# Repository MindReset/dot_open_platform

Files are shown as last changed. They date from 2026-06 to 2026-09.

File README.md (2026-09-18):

# Dot Open Platform

Dot Open Platform is the public resource repository for MindReset open devices and device capabilities. It provides mechanical files, firmware bring-up resources, pin maps, display integration notes, local device protocols, examples, and machine-readable metadata for platforms that present or index Dot device materials.

Resources cover Quote/0 hardware, Rand/0 local Display Mode, and Read Pico enclosure design and firmware development.

## Available Resources

| Product | Package | Included resources |
| --- | --- | --- |
| Quote/0 | `devices/quote_0/` | Enclosure STEP and AdventureX 2026 badge STL files, ESP32-C3 GPIO map, standard and Early Bird Edition display drivers, display waveform/LUT notes, ESP-IDF example, developer documentation |
| Rand/0 Display Mode | `capabilities/rand_0_display_mode/` | Local WebSocket protocol reference and an official browser image-sending example |
| Read Pico | [devices/read_0/](devices/read_0/README.md) | Enclosure STEP model and mechanical notes; official demo firmware, board support, drivers, and pinout links |

## Quick Links

### Quote/0

- [Quote/0 device package](devices/quote_0/README.md)
- [Quote/0 manifest](devices/quote_0/manifest.json)
- [Quote/0 enclosure resources](devices/quote_0/enclosure/README.md)
- [Quote/0 enclosure STEP](devices/quote_0/enclosure/step/quote_0-enclosure.step)
- [AdventureX 2026 badge front STL](devices/quote_0/enclosure/stl/adventurex-2026/quote_0-adventurex-2026-badge-front.stl)
- [AdventureX 2026 badge back cover STL](devices/quote_0/enclosure/stl/adventurex-2026/quote_0-adventurex-2026-badge-back-cover.stl)
- [Quote/0 GPIO pinout](devices/quote_0/firmware-resources/gpio/pinout.md)
- [Display resources](devices/quote_0/firmware-resources/display/README.md)
- [Display driver selection](devices/quote_0/firmware-resources/display/driver-selection.md)
- [Custom firmware guide](devices/quote_0/docs/custom-firmware-guide.md)

### Rand/0

- [Rand/0 Display Mode capability](capabilities/rand_0_display_mode/README.md)
- [Rand/0 browser example](capabilities/rand_0_display_mode/examples/web/display_ws_test.html)

### Read Pico

- [Read Pico hardware and firmware entry](devices/read_0/README.md)
- [Read Pico enclosure resources](devices/read_0/enclosure/README.md)
- [Read Pico enclosure STEP](devices/read_0/enclosure/step/read_0-enclosure.step)
- [Read Pico official firmware repository](https://github.com/MindReset/read_pico_firmware)

### Repository

- [Repository license](LICENSE.md)
- [Authors](AUTHORS)
- [Maintainers](MAINTAINERS)

## Official Online Resources

For a product-level overview of the Dot developer ecosystem, visit the [Dot Developer Platform](https://dot.mindreset.tech/developers).

The links below point to reference documentation and community resources that are most relevant when using this repository:

### Product Documentation

| Resource | What it helps you do |
| --- | --- |
| [Quote/0 Docs](https://dot.mindreset.tech/docs/quote_0) | Learn how Quote/0 works, including setup, firmware, and user-facing device behavior. |
| [Rand/0 Docs](https://dot.mindreset.tech/docs/rand_0) | Device features, setup, and local Display Mode. |
| [Read Pico Docs](https://dot.mindreset.tech/docs/read_0) | Product specifications, official demos, and firmware development. |

### Developer APIs and Skills

| Resource | What it helps you do |
| --- | --- |
| [Developer Platform Docs](https://dot.mindreset.tech/docs/service/open) | Create API keys, find device IDs, read device status, update device settings, and control device content. |
| [Text API](https://dot.mindreset.tech/docs/service/open/text_api) | Send text content to Dot devices. |
| [Image API](https://dot.mindreset.tech/docs/service/open/image_api) | Send image content to Dot devices. |
| [Canvas API](https://dot.mindreset.tech/docs/service/open/canvas_api) | Create structured visual content for Dot devices. |
| [Skills](https://dot.mindreset.tech/docs/service/open/skill) | Build reusable device content workflows. |

### Content and Community

| Resource | What it helps you do |
| --- | --- |
| [Content Studio](https://dot.mindreset.tech/docs/service/studio) | Create and manage rich Dot content without writing a full firmware stack. |
| [Community Co-Creation](https://dot.mindreset.tech/docs/service/co_create) | Browse community-built Dot integrations and examples. |
| [Software Co-Creation](https://dot.mindreset.tech/docs/service/co_create/software) | Explore API clients, automations, MCP integrations, dashboards, and software workflows. |
| [Hardware Co-Creation](https://dot.mindreset.tech/docs/service/co_create/hardware) | Explore community mounts, stands, cases, and other hardware accessories. |

## Repository Layout

```text
devices/
  quote_0/
    README.md
    manifest.json
    enclosure/
    firmware-resources/
    docs/
    examples/
  read_0/
    README.md
    manifest.json
    enclosure/
capabilities/
  rand_0_display_mode/
    README.md
    protocol.md
    examples/
```

Each device package is intended to be useful in two ways:

1. People can read the documentation directly on GitHub or another public platform.
2. Tools can read `manifest.json` to locate downloadable files and device metadata.

## What Is Included for Quote/0

- A STEP enclosure model exported in millimeter units.
- A two-part AdventureX 2026 badge enclosure provided as binary STL meshes.
- GPIO documentation for the ESP32-C3 pins used by the current Quote/0 hardware design.
- Minimal ESP-IDF display drivers for the 152 x 296 monochrome e-paper display.
- Documentation for selecting the standard or Early Bird Edition display driver.
- Documentation for the included full-refresh waveform/LUT data.
- A minimal ESP-IDF example showing how to initialize and refresh the display.
- Licensing, attribution, contribution, support, and security documentation.

## What Is Included for Rand/0 Display Mode

- A protocol reference for the Rand/0 `200 × 200` local display endpoints.
- An official dependency-free browser example for sending black-and-white or four-level grayscale images.
- Button event handling and local-network security guidance.

## Using These Materials

Start with the [Quote/0 getting started guide](devices/quote_0/docs/getting-started.md). If you are building custom firmware, continue with the [custom firmware guide](devices/quote_0/docs/custom-firmware-guide.md) and the [display integration guide](devices/quote_0/docs/display-integration.md).

If you are working on the enclosure, start with the [enclosure README](devices/quote_0/enclosure/README.md) and inspect the applicable STEP or STL files in your CAD or slicing tool before manufacturing or printing.

If you are building a local Rand/0 display tool, start with the [Rand/0 Display Mode capability](capabilities/rand_0_display_mode/README.md) and its [protocol reference](capabilities/rand_0_display_mode/protocol.md).

For Read Pico, start with the [resource entry](devices/read_0/README.md). Use the [enclosure resources](devices/read_0/enclosure/README.md) for custom cases and accessories, or continue in the [official firmware repository](https://github.com/MindReset/read_pico_firmware) for firmware development.

## License Summary

This repository uses multiple licenses:

- Software source code: Apache-2.0
- Hardware design material: CERN-OHL-P-2.0
- Documentation and media: CC BY 4.0

See [LICENSE.md](LICENSE.md) and [NOTICE.md](NOTICE.md) before redistributing modified material.

## No Warranty

These resources are provided as open hardware reference material. Verify electrical limits, enclosure tolerances, battery handling, and display behavior before using the files in a production or safety-sensitive context.

MindReset cannot guarantee the security of custom firmware flashed to devices. Flashing custom firmware voids the device warranty. Device-specific safety notes are documented in each custom firmware guide, starting with the [Quote/0 custom firmware guide](devices/quote_0/docs/custom-firmware-guide.md).

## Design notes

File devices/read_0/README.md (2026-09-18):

# Read Pico

Read Pico is an ESP32-S3 development board with a 4.7-inch e-paper display, native 16-level grayscale, two-point touch, three touch keys, microSD storage, and USB-C. The product belongs to the Read series.

## Official firmware and hardware references

**[Open the official demo firmware repository](https://github.com/MindReset/read_pico_firmware)**

The firmware repository contains the factory demo, board support, chip drivers, pin assignments, display waveforms, and ESP-IDF build instructions. Its demos cover display refresh, touch, acceleration, power, storage, fonts, and sleep/wake behavior.

This Open Platform package includes the enclosure model and links to firmware resources. Firmware, drivers, and firmware assets are maintained in the dedicated repository and are not duplicated here.

| Resource | Link |
| --- | --- |
| Enclosure model and mechanical notes | [Enclosure resources](enclosure/README.md) |
| Enclosure STEP download | [read_0-enclosure.step](enclosure/step/read_0-enclosure.step) |
| Official firmware, board support, and pinout | [read_pico_firmware](https://github.com/MindReset/read_pico_firmware) |
| Product documentation | [Read Pico](https://dot.mindreset.tech/docs/read_0) |
| Official demo guide | [Getting started](https://dot.mindreset.tech/docs/read_0/start) |
| Build and flash | [Firmware guide](https://dot.mindreset.tech/docs/read_0/firmware) |
| Machine-readable resource index | [manifest.json](manifest.json) |

The firmware currently requires ESP-IDF v6.1 and targets ESP32-S3. Follow its README for board-specific timing and VCOM handling. Firmware and bundled components follow the licenses in that repository; this entry does not relicense those resources.

## Enclosure and Accessories

Use the [enclosure STEP model](enclosure/step/read_0-enclosure.step) to design custom cases, mounts, and accessories. The model uses millimeter units and is provided in STEP AP242 format.

Read the [enclosure notes](enclosure/README.md) before modifying or manufacturing parts. The enclosure is licensed under CERN-OHL-P-2.0; documentation follows CC BY 4.0.

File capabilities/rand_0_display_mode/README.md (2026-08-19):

# Rand/0 Display Mode

Rand/0 Display Mode lets you build a small local tool that sends custom images to the device and receives its button events. It is a direct LAN connection: no Dot. App, Dot API, or custom firmware is required.

This package documents the Display Mode protocol implemented by Rand/0 firmware `1.3.1` and includes an official browser example.

## Quick start

Before you begin:

- Complete Wi-Fi Time Sync once so Rand/0 remembers a Wi-Fi network.
- Keep Rand/0 charged or connected to power.
- Connect your computer and Rand/0 to the same local network.

1. On Rand/0, open **Main menu → More → Display**.
2. Wait for the device to show its local IP address.
3. Serve the browser example from this directory:

   ```sh
   cd examples/web
   python3 -m http.server 8765
   ```

4. Open <http://127.0.0.1:8765/display_ws_test.html>.
5. Enter the IP address shown on Rand/0, connect, choose an image, and send it.

The device exits Display Mode when you long-press the top button.

## Example

- [Browser example](examples/web/display_ws_test.html)
- [Protocol reference](protocol.md)

The example is a dependency-free HTML file. It resizes an image to `200 × 200`, converts it to the selected frame format in the browser, sends it over WebSocket, and displays button events returned by Rand/0.

## Network and security

Display Mode is intended for a trusted local network. The device exposes its WebSocket endpoints without additional login authentication. Do not forward the device port to the internet or send sensitive content while using this capability.

The device allows one active client at a time. A new connection replaces the previous one, and frames sent faster than the e-ink display can refresh may be dropped so that only the latest frame is kept.

This is a device-local capability, not a Dot cloud API. It does not provide device identity, remote access, or firmware customization.

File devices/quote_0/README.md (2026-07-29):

# Quote/0

Quote/0 is a smart e-ink Dot device published by MindReset. It is designed for calm, glanceable information in everyday spaces and can display app-configured content such as RSS feeds, to-dos, calendars, weather, and custom API-driven updates.

This open device package collects the public files needed to inspect the enclosure, understand the hardware pin map, and build custom firmware that drives the e-paper display.

## Package Contents

| Area | Path | Contents |
| --- | --- | --- |
| Device metadata | `manifest.json` | Machine-readable device and asset index |
| Enclosure | `enclosure/` | Main STEP model, AdventureX 2026 badge STL files, and mechanical documentation |
| GPIO | `firmware-resources/gpio/` | ESP32-C3 pinout in Markdown, CSV, and JSON |
| Display | `firmware-resources/display/` | Standard and Early Bird Edition display drivers, waveform/LUT notes, and integration docs |
| Guides | `docs/` | Getting started, hardware overview, custom firmware, display integration, enclosure notes, FAQ |
| Examples | `examples/` | Minimal ESP-IDF display example |

## Hardware Summary

| Item | Value |
| --- | --- |
| Main MCU | ESP32-C3 |
| Display controller | UC8251D for standard edition; UC8151/IL0324 for Early Bird Edition |
| Display resolution | 152 x 296 |
| Display colors | 1-bit monochrome, white/black |
| Display buffer size | 5,624 bytes |
| Display bus | SPI, MOSI-only, no MISO |
| Console | USB-Serial-JTAG |
| Enclosure files | STEP AP242 exchange file and binary STL meshes |

## Official Online Resources

| Resource | Link |
| --- | --- |
| Developer Platform | https://dot.mindreset.tech/developers |
| Quote/0 product docs | https://dot.mindreset.tech/docs/quote_0 |
| Developer Platform docs | https://dot.mindreset.tech/docs/service/open |
| Text API | https://dot.mindreset.tech/docs/service/open/text_api |
| Image API | https://dot.mindreset.tech/docs/service/open/image_api |
| Canvas API | https://dot.mindreset.tech/docs/service/open/canvas_api |
| Skills | https://dot.mindreset.tech/docs/service/open/skill |
| Content Studio | https://dot.mindreset.tech/docs/service/studio |
| Community Co-Creation | https://dot.mindreset.tech/docs/service/co_create |
| Software Co-Creation | https://dot.mindreset.tech/docs/service/co_create/software |
| Hardware Co-Creation | https://dot.mindreset.tech/docs/service/co_create/hardware |

## Quick Start

1. Review the [getting started guide](docs/getting-started.md).
2. Check the [GPIO pinout](firmware-resources/gpio/pinout.md).
3. Read the [display resources](firmware-resources/display/README.md).
4. Try the [ESP-IDF minimal display example](examples/esp-idf/minimal-display/README.md).
5. Review the [enclosure resources](enclosure/README.md) and inspect the applicable STEP or STL files in your CAD or slicing tool.

## Firmware Bring-Up Path

For a custom firmware port, start with the files in this order:

1. `firmware-resources/gpio/pinout.md`
2. `firmware-resources/display/driver-selection.md`
3. `firmware-resources/display/README.md`
4. Standard edition: `firmware-resources/display/drivers/uc8251d_minimal.h` and `firmware-resources/display/drivers/uc8251d_minimal.c`
5. Early Bird Edition: `firmware-resources/display/drivers/uc8151_minimal.h` and `firmware-resources/display/drivers/uc8151_minimal.c`
6. `examples/esp-idf/minimal-display/`

The minimal display drivers are intentionally small. They focus on initializing the selected panel, sending a full-frame 1bpp buffer, clearing the panel, and entering sleep.

## Custom Firmware Safety

MindReset cannot guarantee the security of custom firmware flashed to Quote/0, and flashing custom firmware voids the device warranty. Before building firmware, read the [custom firmware guide](docs/custom-firmware-guide.md), especially the ESP-IDF console configuration, deep-sleep recovery, and power-on sequence notes.

Use Pure USB Serial/JTAG for ESP-IDF console output. The default UART console pins may conflict with `GPIO20`, which controls display power.

## Mechanical Files

The package includes the main Quote/0 STEP enclosure model and a two-part AdventureX 2026 badge enclosure:

```text
enclosure/step/quote_0-enclosure.step
enclosure/stl/adventurex-2026/quote_0-adventurex-2026-badge-front.stl
enclosure/stl/adventurex-2026/quote_0-adventurex-2026-badge-back-cover.stl
```

The STEP file supports inspection, derivative mechanical work, and manufacturing preparation. The AdventureX 2026 binary STL files provide a printable front shell and back cover. Always verify units, tolerances, wall thicknesses, mounting features, and material behavior before production.

## Platform Metadata

Platforms that need a stable inventory should read:

```text
devices/quote_0/manifest.json
```

The manifest lists the device name, hardware summary, resource paths, license scopes, and files included in the current public package.

## Licensing

- Software source code: Apache-2.0
- Hardware design material: CERN-OHL-P-2.0
- Documentation and media: CC BY 4.0

See the repository [license](../../LICENSE.md) and [notice](../../NOTICE.md) for details.

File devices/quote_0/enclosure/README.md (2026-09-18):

# Quote/0 Enclosure

This folder contains public mechanical resources for the Quote/0 enclosure.

## Included Files

| File | Format | Notes |
| --- | --- | --- |
| `step/quote_0-enclosure.step` | STEP AP242 | Main Quote/0 enclosure, exported from Shapr3D in millimeter units |
| `stl/adventurex-2026/quote_0-adventurex-2026-badge-front.stl` | Binary STL | AdventureX 2026 badge enclosure front shell |
| `stl/adventurex-2026/quote_0-adventurex-2026-badge-back-cover.stl` | Binary STL | AdventureX 2026 badge enclosure back cover |

The STEP header identifies MindReset and Quote/0, includes the source URL and license identifier, and preserves the export timestamp `2026-06-12T22:04:06+08:00`.

## Folder Layout

| Folder | Purpose |
| --- | --- |
| `step/` | STEP exchange files |
| `stl/adventurex-2026/` | Printable meshes for the AdventureX 2026 badge enclosure |

## AdventureX 2026 Badge Enclosure

The AdventureX 2026 badge enclosure is an alternate two-part Quote/0 shell created for the AdventureX 2026 hackathon. Use the front shell and back cover together.

Design credit: [AdventureX 2026](https://adventure-x.org/en). Published by MindReset.

Each binary STL header identifies MindReset, Quote/0, the part, AdventureX 2026 as the designer, and CERN-OHL-P-2.0. Binary STL headers are limited to 80 bytes; full source and attribution details are provided here.

- Source: [MindReset Dot Open Platform](https://github.com/MindReset/dot_open_platform)
- Official website: [Dot by MindReset](https://dot.mindreset.tech)

These STEP and STL file-level markings do not add an embossed or engraved logo to the geometry.

## Usage Notes

- Inspect the STEP file in a CAD tool before machining, printing, or modifying the design.
- STL files do not encode units. Import the AdventureX 2026 meshes as millimeters and verify their scale before printing.
- Confirm tolerances against the exact display, PCB, battery, fasteners, and materials you use.
- STEP is an exchange format. If you need parametric editing, rebuild the model in your CAD tool or wait for a native source file release.
- No official drawing, render, or print profile is included. Print orientation, material, nozzle size, shrinkage, and post-processing all affect the result.

## License

Hardware design material in this folder is licensed under [CERN-OHL-P-2.0](../../../LICENSES/CERN-OHL-P-2.0.txt) unless a file states otherwise.

When redistributing modified designs, credit MindReset and retain the AdventureX design credit for the badge enclosure. See [NOTICE.md](../../../NOTICE.md) and the [trademark terms](../../../LICENSE.md#trademarks).

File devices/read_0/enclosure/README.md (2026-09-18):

# Read Pico Enclosure

Use the Read Pico enclosure model to design custom cases, mounts, and accessories.

## Included Files

| File | Format | Notes |
| --- | --- | --- |
| [read_0-enclosure.step](step/read_0-enclosure.step) | STEP AP242 | Read Pico enclosure, exported from Shapr3D in millimeter units; contains two solid bodies |

The source model was exported on `2026-09-17T18:39:30+08:00`. The STEP header identifies MindReset and Read Pico and includes the source URL and license identifier. These file-level markings do not add an embossed or engraved logo to the geometry.

## Usage Notes

- Open the STEP file in your CAD tool with millimeter units to inspect or modify the enclosure.
- Check dimensions, wall thickness, assembly clearances, display alignment, and access to ports and controls against your actual device before manufacturing.
- Confirm fit and tolerances for your chosen materials and process when designing cases, mounts, or other accessories.
- STEP is a CAD exchange format, not a native parametric source file. Rebuild editable features as needed in your CAD tool.
- No STL export, dimensioned drawing, or print profile is included. Export your modified design to a suitable format and verify its scale before printing or machining.

## License and Attribution

Hardware design material in this folder is licensed under [CERN-OHL-P-2.0](../../../LICENSES/CERN-OHL-P-2.0.txt).

Recommended attribution:

```text
This project is based on Read Pico enclosure design and public materials by MindReset.
Hardware source: MindReset
Official link: https://dot.mindreset.tech
```

See [NOTICE.md](../../../NOTICE.md) and the [trademark terms](../../../LICENSE.md#trademarks) when redistributing modified designs.

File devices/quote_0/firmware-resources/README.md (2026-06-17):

# Quote/0 Firmware Resources

This folder contains the public hardware-facing files needed to bring up custom Quote/0 firmware.

## Contents

| Folder | Purpose |
| --- | --- |
| `gpio/` | ESP32-C3 pin usage table in human-readable and machine-readable formats |
| `display/` | Standard and Early Bird Edition e-paper drivers, display constants, waveform/LUT notes, and initialization guidance |

## Firmware Assumptions

- MCU: ESP32-C3
- Console: Pure USB Serial/JTAG, with `ESP_CONSOLE_UART_DEFAULT` disabled and `ESP_CONSOLE_USB_SERIAL_JTAG` enabled
- Display bus: SPI using MOSI and CLK, with no MISO line
- Display power is controlled by a dedicated GPIO
- Display framebuffer format is 1 bit per pixel, where `1` means white and `0` means black

These files are intended as reference material. Verify the exact hardware revision before using them in production firmware.

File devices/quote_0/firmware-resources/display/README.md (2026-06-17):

# Quote/0 Display Resources

Quote/0 uses a 152 x 296 monochrome e-paper display. There are two display driver variants: the standard edition uses the UC8251D driver, while the Early Bird Edition uses the UC8151/IL0324 driver.

Before porting firmware, read [driver-selection.md](driver-selection.md) and choose the driver that matches the edition shown in the Dot. App device details.

## Display Summary

| Item | Value |
| --- | --- |
| Controller | UC8251D for standard edition; UC8151/IL0324 for Early Bird Edition |
| Resolution | 152 x 296 |
| Color mode | Black and white |
| Pixel format | 1 bit per pixel |
| Pixel value | `1 = white`, `0 = black` |
| Framebuffer size | 5,624 bytes |
| Bus | SPI |

## Files

| Path | Purpose |
| --- | --- |
| `driver-selection.md` | Rules for choosing the standard or Early Bird Edition display driver |
| `drivers/uc8251d_minimal.h` | Standard edition public interface and display configuration structure |
| `drivers/uc8251d_minimal.c` | Standard edition ESP-IDF implementation for UC8251D full-frame refresh |
| `drivers/uc8151_minimal.h` | Early Bird Edition public interface and display configuration structure |
| `drivers/uc8151_minimal.c` | Early Bird Edition ESP-IDF implementation for UC8151/IL0324 full-frame refresh |
| `waveforms/README.md` | Notes on the included full-refresh waveform/LUT data |
| `init-sequences/README.md` | Initialization sequence notes |

## Standard Edition Minimal Usage

Use this path unless the Dot. App device details show the Early Bird Edition label.

```c
#include <string.h>
#include "uc8251d_minimal.h"

static const uc8251d_config_t display_config = {
    .spi_host = SPI2_HOST,
    .pin_vin = 20,
    .pin_busy = 3,
    .pin_reset = 4,
    .pin_dc = 5,
    .pin_cs = 6,
    .pin_sck = 10,
    .pin_mosi = 7,
    .spi_clock_hz = 15 * 1000 * 1000,
};

void app_main(void)
{
    uc8251d_init(&display_config);
    uc8251d_clear(true);

    uint8_t frame[UC8251D_BUFFER_SIZE];
    memset(frame, 0xFF, sizeof(frame));

    uc8251d_display(frame);
    uc8251d_sleep();
}
```

## Early Bird Edition Minimal Usage

Use this path only when the Dot. App device details show `首发版`, `Early Bird Edition`, or `先発版です`.

```c
#include <string.h>
#include "uc8151_minimal.h"

static const uc8151_config_t display_config = {
    .spi_host = SPI2_HOST,
    .pin_vin = 20,
    .pin_busy = 3,
    .pin_reset = 4,
    .pin_dc = 5,
    .pin_cs = 6,
    .pin_sck = 10,
    .pin_mosi = 7,
    .spi_clock_hz = 15 * 1000 * 1000,
};

void app_main(void)
{
    uc8151_init(&display_config);
    uc8151_clear(true);

    uint8_t frame[UC8151_BUFFER_SIZE];
    memset(frame, 0xFF, sizeof(frame));

    uc8151_display(frame);
    uc8151_sleep();
}
```

## Scope

The minimal drivers only cover the public bring-up paths needed by Quote/0:

- SPI bus setup.
- Panel reset and busy polling.
- Full-frame 1bpp refresh.
- White or black clear.
- Display sleep and power control.

It does not include automatic display detection, multi-panel abstraction, image decoding, partial refresh, UI rendering, or application logic.

## License

Driver source files are licensed under Apache-2.0. Display hardware notes and waveform documentation are licensed under CERN-OHL-P-2.0 or CC BY 4.0 according to the repository license policy.

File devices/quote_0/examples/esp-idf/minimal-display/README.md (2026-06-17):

# Quote/0 ESP-IDF Minimal Display Example

This example shows how to initialize the standard edition Quote/0 UC8251D display, write a simple 1bpp pattern, refresh the screen, and enter sleep.

If the Dot. App device details show `首发版`, `Early Bird Edition`, or `先発版です`, use the Early Bird Edition UC8151/IL0324 driver instead. See:

```text
../../../firmware-resources/display/driver-selection.md
```

## Requirements

- ESP-IDF installed and configured.
- Quote/0 hardware or compatible wiring.
- Standard edition UC8251D display with the Quote/0 152 x 296 monochrome panel configuration.

## Files

| File | Purpose |
| --- | --- |
| `CMakeLists.txt` | ESP-IDF project file |
| `main/CMakeLists.txt` | Main component definition |
| `main/quote_0_minimal_display_example.c` | Example application |

The example builds against the public driver in:

```text
../../../firmware-resources/display/drivers/
```

## Usage

From this folder, use the normal ESP-IDF flow:

```sh
idf.py set-target esp32c3
idf.py build
idf.py flash monitor
```

## Expected Behavior

The firmware clears the screen to white, draws a small black border pattern into a framebuffer, refreshes the display, and enters display sleep.

## Notes

- The example does not configure Wi-Fi, Bluetooth LE, storage, or application UI.
- If your hardware wiring differs from Quote/0, update `display_config` in the example source file.
- If the display does not refresh, check power, reset, BUSY, CS, MOSI, CLK, and the SPI host.

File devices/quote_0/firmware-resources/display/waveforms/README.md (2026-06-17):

# Quote/0 Waveform Notes

Quote/0 includes separate waveform/LUT data for the standard edition and the Early Bird Edition.

Use the waveform data only with the matching display driver. The screen parameters are the same, but the controller firmware and waveform requirements differ.

## Driver Selection

Use the Early Bird Edition waveform only when the Dot. App device details show `首发版`, `Early Bird Edition`, or `先発版です`.

If the device details do not show one of these edition labels, use the standard edition waveform.

## Standard Edition LUT

The standard edition UC8251D driver includes a full-refresh waveform/LUT table named `s_lut_gc` in:

```text
../drivers/uc8251d_minimal.c
```

The waveform data is redistributed here as part of the public Quote/0 display resources, based on the assumption that MindReset is authorized to publish and redistribute it.

### LUT Layout

The table contains 376 bytes split across the UC8251D LUT command registers:

| Command | Offset | Length |
| --- | ---: | --- |
| `0x20` | `0` | `80` |
| `0x21` | `80` | `56` |
| `0x22` | `136` | `80` |
| `0x23` | `216` | `80` |
| `0x24` | `296` | `80` | 

The driver loads the LUT before writing the old and new frame planes, then triggers a full display update with command `0x12`.

## Early Bird Edition LUT

The Early Bird Edition UC8151/IL0324 driver stores separate full-refresh LUT arrays in:

```text
../drivers/uc8151_minimal.c
```

| Command | Array | Length |
| --- | --- | --- |
| `0x20` | `s_lut_vcom` | `44` |
| `0x21` | `s_lut_ww` | `42` | 
| `0x22` | `s_lut_bw` | `42` | 
| `0x23` | `s_lut_wb` | `42` | 
| `0x24` | `s_lut_bb` | `42` | 

The Early Bird Edition driver loads the LUT during panel initialization, then triggers a full display update with command `0x12`.

## Integration Rules

- Use each LUT with its matching driver and the Quote/0 152 x 296 monochrome panel configuration.
- Keep the framebuffer format as 1bpp, where `1` means white and `0` means black.
- If you replace the display panel, validate the controller, resolution, voltage behavior, and waveform requirements before reusing this LUT.

## License

Waveform-related display resources in this package are published under the repository hardware/documentation license policy. Check `LICENSE.md` and `NOTICE.md` before redistributing modified versions.

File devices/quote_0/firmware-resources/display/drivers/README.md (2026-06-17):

# Quote/0 Minimal Display Drivers

This folder contains minimal ESP-IDF display drivers for Quote/0.

Quote/0 uses two display driver variants. The screen size and framebuffer format are the same, but the controller firmware and waveform data differ.

## Which Driver to Use

Use the standard driver unless the Dot. App device details show an Early Bird Edition label.

| Dot. App locale | Device name | Edition label | Driver |
| --- | --- | --- | --- |
| `zh-Hans-CN` | `摘录/0` | `首发版` | `uc8151_minimal.*` |
| `en-US` | `Quote/0` | `Early Bird Edition` | `uc8151_minimal.*` |
| `ja-JP` | `Quote/0` | `先発版です` | `uc8151_minimal.*` |

If the device details do not show one of the edition labels above, use the standard driver:

```text
uc8251d_minimal.*
```

## Files

| File | Purpose |
| --- | --- |
| `uc8251d_minimal.h` | Standard edition public interface, dimensions, buffer size, and GPIO configuration structure |
| `uc8251d_minimal.c` | Standard edition UC8251D SPI/GPIO implementation, initialization sequence, full-refresh waveform/LUT, clear, display, and sleep functions |
| `uc8151_minimal.h` | Early Bird Edition public interface, dimensions, buffer size, and GPIO configuration structure |
| `uc8151_minimal.c` | Early Bird Edition UC8151/IL0324 SPI/GPIO implementation, initialization sequence, full-refresh waveform/LUT, clear, display, and sleep functions |

## Standard Edition API

```c
esp_err_t uc8251d_init(const uc8251d_config_t *config);
esp_err_t uc8251d_display(const uint8_t *data);
esp_err_t uc8251d_clear(bool white);
esp_err_t uc8251d_sleep(void);
```

## Early Bird Edition API

```c
esp_err_t uc8151_init(const uc8151_config_t *config);
esp_err_t uc8151_display(const uint8_t *data);
esp_err_t uc8151_clear(bool white);
esp_err_t uc8151_sleep(void);
```

## Framebuffer Format

- Width: `152`
- Height: `296`
- Buffer size: `5624` bytes
- Pixel format: 1 bit per pixel
- Pixel value: `1 = white`, `0 = black`

## Porting Notes

- Change the selected config type if your GPIO wiring differs from Quote/0.
- Keep MISO disabled unless your hardware adds a display read path.
- Keep the display power pin high while resetting, writing, and refreshing the panel.
- Call the matching sleep function after refresh if your firmware needs low-power behavior.

## License

The driver source code is licensed under Apache-2.0.

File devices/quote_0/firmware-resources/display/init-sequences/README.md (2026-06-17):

# Quote/0 Display Initialization Sequence Notes

The public initialization sequences are implemented in:

```text
../drivers/uc8251d_minimal.c
../drivers/uc8151_minimal.c
```

Use `uc8251d_minimal.*` for standard edition devices. Use `uc8151_minimal.*` only when the Dot. App device details show `首发版`, `Early Bird Edition`, or `先発版です`.

The main bring-up flow is:

1. Configure display GPIOs.
2. Enable display power through `GPIO20`.
3. Initialize the SPI bus with MOSI and CLK only.
4. Reset the panel.
5. Wait for BUSY to become ready.
6. Configure panel settings, power settings, booster soft start, resolution, PLL, TCON, VCOM, and border behavior.
7. Power on the panel and wait for BUSY.
8. Load the full-refresh LUT.
9. Write old and new image planes.
10. Trigger display refresh.
11. Enter sleep when the update is complete.

## Quote/0 Default Pins

| Signal | GPIO |
| --- | ---: |
| VIN | 20 |
| BUSY | 3 |
| RESET | 4 |
| DC | 5 |
| CS | 6 |
| MOSI | 7 |
| CLK | 10 |

## Notes

- The standard edition driver polls BUSY with command `0x71`.
- The Early Bird Edition driver polls BUSY by reading the BUSY GPIO directly.
- The default SPI clock is 15 MHz when `spi_clock_hz` is not provided.
- The display sleep path sends the controller-specific sleep sequence, then releases the display power control pin.

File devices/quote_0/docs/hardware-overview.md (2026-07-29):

# Quote/0 Hardware Overview

This overview summarizes the public hardware-facing details currently available for Quote/0.

## MCU

Quote/0 uses an ESP32-C3 MCU.

For custom ESP-IDF firmware, use Pure USB Serial/JTAG console output. The default UART console pins may conflict with `GPIO20`, which controls display power. In `menuconfig`, disable `ESP_CONSOLE_UART_DEFAULT` and enable `ESP_CONSOLE_USB_SERIAL_JTAG`.

## Power-Related Signals

| GPIO | Function | Notes |
| --- | --- | --- |
| GPIO0 | VBUS detect | High level means USB or external power is present |
| GPIO1 | Battery voltage sample | ADC input through an internal 50% / 50% resistor divider |
| GPIO20 | E-paper VIN | Controls display power |

## Display Interface

The e-paper display uses an SPI write path:

| Signal | GPIO |
| --- | ---: |
| BUSY | 3 |
| RESET | 4 |
| DC | 5 |
| CS | 6 |
| MOSI | 7 |
| CLK | 10 |
| VIN | 20 |

MISO is not used.

## Display Panel

| Item | Value |
| --- | --- |
| Standard edition controller path | UC8251D |
| Early Bird Edition controller path | UC8151/IL0324 |
| Resolution | 152 x 296 |
| Colors | White and black |
| Pixel format | 1bpp |
| Buffer size | 5,624 bytes |

The visible display parameters are the same across the standard edition and Early Bird Edition, but their controller firmware and waveform data differ. Use the Early Bird Edition driver only when the Dot. App device details show `首发版`, `Early Bird Edition`, or `先発版です`.

## Enclosure

The current mechanical release includes the main enclosure as a STEP AP242 file exported in millimeter units:

```text
enclosure/step/quote_0-enclosure.step
```

It also includes the two-part AdventureX 2026 badge enclosure as binary STL meshes:

```text
enclosure/stl/adventurex-2026/quote_0-adventurex-2026-badge-front.stl
enclosure/stl/adventurex-2026/quote_0-adventurex-2026-badge-back-cover.stl
```

## Current Public Scope

This package currently publishes the resources needed for:

- Enclosure inspection, derivative mechanical work, and printing of the AdventureX 2026 badge enclosure.
- GPIO mapping.
- Display initialization and full-frame refresh.
- Minimal ESP-IDF firmware bring-up.

It does not currently publish PCB source files, schematic PDFs, native parametric CAD files, manufacturing drawings, or complete product firmware.

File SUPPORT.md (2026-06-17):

# Support

Use GitHub issues for public questions about:

- Missing or unclear documentation.
- GPIO and display integration problems.
- Enclosure file issues.
- Example firmware bring-up problems.
- Manifest or repository structure problems.

When reporting a hardware or firmware issue, include:

- Device: `Quote/0`
- Hardware revision, if known
- Firmware framework and version, if relevant
- File path or documentation section involved
- Clear reproduction steps or photos/screenshots when useful

Do not post private credentials, API keys, unreleased supplier files, or private manufacturing documents.

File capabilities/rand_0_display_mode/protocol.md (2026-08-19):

# Rand/0 Display Mode Protocol

This document describes the WebSocket protocol implemented by Rand/0 firmware `1.3.1`.

## Connection

Enter Display Mode from **Main menu → More → Display**. Rand/0 connects to a remembered Wi-Fi network and shows its local IP address when ready.

Connect to one of these endpoints:

| Endpoint | Binary frame | Format |
| --- | ---: | --- |
| `ws://<IP>/display/bw` | Exactly `5,000` bytes | 1 bit per pixel, black and white |
| `ws://<IP>/display/gray4` | Exactly `10,000` bytes | 2 bits per pixel, four gray levels |

The display is `200 × 200` pixels. Send one binary frame for each image.

## Frame encoding

Pixels are packed row by row, from left to right and then top to bottom. The highest bits represent the leftmost pixels.

### Black and white

- `1` means white; `0` means black.
- Each byte contains 8 pixels.
- The first pixel uses bit 7.

### Four gray levels

- Each pixel uses 2 bits.
- `00` is white, `01` is light gray, `10` is dark gray, and `11` is black.
- Each byte contains 4 pixels.
- The first pixel uses bits 7–6.

## Device messages

Rand/0 sends text JSON messages for button events and errors. A short press looks like this:

```json
{"type":"key","key":"up","action":"short"}
```

Possible frame errors include:

```json
{"type":"error","error":"expected_binary_5000"}
{"type":"error","error":"expected_binary_10000"}
{"type":"error","error":"inactive_client"}
{"type":"error","error":"no_memory"}
{"type":"error","error":"queue_busy"}
```

## Limits

- Only one client is active at a time. A new connection replaces the previous client.
- If the display is still refreshing when another frame arrives, Rand/0 keeps the latest frame and may drop intermediate frames.
- The connection has no additional login authentication. Use it only on a trusted local network.

## Minimal example

```js
const socket = new WebSocket("ws://192.168.1.100/display/bw");
socket.binaryType = "arraybuffer";
socket.onopen = () => socket.send(new Uint8Array(5000).fill(0xff));
socket.onmessage = (event) => console.log(event.data);
```

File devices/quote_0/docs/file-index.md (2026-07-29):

# File Index

This index lists the public Quote/0 package files and their intended purpose.

## Device Package

| File | Purpose |
| --- | --- |
| `README.md` | Human-readable Quote/0 landing page |
| `manifest.json` | Machine-readable device and asset inventory |

## Enclosure

| File | Purpose |
| --- | --- |
| `enclosure/README.md` | Mechanical resource overview |
| `enclosure/step/quote_0-enclosure.step` | STEP enclosure model |
| `enclosure/stl/adventurex-2026/quote_0-adventurex-2026-badge-front.stl` | AdventureX 2026 badge enclosure front shell |
| `enclosure/stl/adventurex-2026/quote_0-adventurex-2026-badge-back-cover.stl` | AdventureX 2026 badge enclosure back cover |

## Firmware Resources

| File | Purpose |
| --- | --- |
| `firmware-resources/README.md` | Firmware resource overview |
| `firmware-resources/gpio/pinout.md` | Human-readable GPIO table |
| `firmware-resources/gpio/pinout.csv` | CSV GPIO table |
| `firmware-resources/gpio/pinout.json` | JSON GPIO table |
| `firmware-resources/display/README.md` | Display resource overview |
| `firmware-resources/display/driver-selection.md` | Standard vs Early Bird Edition display driver selection |
| `firmware-resources/display/drivers/README.md` | Display driver notes |
| `firmware-resources/display/drivers/uc8251d_minimal.h` | Standard edition public driver header |
| `firmware-resources/display/drivers/uc8251d_minimal.c` | Standard edition minimal driver implementation |
| `firmware-resources/display/drivers/uc8151_minimal.h` | Early Bird Edition public driver header |
| `firmware-resources/display/drivers/uc8151_minimal.c` | Early Bird Edition minimal driver implementation |
| `firmware-resources/display/waveforms/README.md` | Waveform/LUT notes |
| `firmware-resources/display/init-sequences/README.md` | Initialization sequence notes |

## Examples

| File | Purpose |
| --- | --- |
| `examples/esp-idf/minimal-display/README.md` | ESP-IDF example guide |
| `examples/esp-idf/minimal-display/CMakeLists.txt` | ESP-IDF project CMake file |
| `examples/esp-idf/minimal-display/main/CMakeLists.txt` | ESP-IDF main component CMake file |
| `examples/esp-idf/minimal-display/main/quote_0_minimal_display_example.c` | Minimal display refresh example |

## Guides

| File | Purpose |
| --- | --- |
| `docs/getting-started.md` | First steps through the package |
| `docs/hardware-overview.md` | Public hardware summary |
| `docs/custom-firmware-guide.md` | Custom firmware bring-up guide |
| `docs/display-integration.md` | Display behavior and porting guide |
| `docs/enclosure-printing.md` | Mechanical and printing notes |
| `docs/faq.md` | Common questions |
| `docs/file-index.md` | This file |

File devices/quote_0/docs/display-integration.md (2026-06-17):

# Display Integration Guide

This guide documents the display behavior exposed in the public Quote/0 package.

## Controller and Panel

Quote/0 uses a monochrome e-paper display with two driver variants. The standard edition uses the UC8251D driver path. The Early Bird Edition uses the UC8151/IL0324 driver path.

| Item | Value |
| --- | --- |
| Width | 152 pixels |
| Height | 296 pixels |
| Buffer size | 5,624 bytes |
| Color depth | 1 bit per pixel |
| White pixel | `1` |
| Black pixel | `0` |

## Driver Selection

Use the Early Bird Edition driver only when the Dot. App device details show one of these labels:

| Dot. App locale | Device name | Edition label | Driver |
| --- | --- | --- | --- |
| `zh-Hans-CN` | `摘录/0` | `首发版` | `uc8151_minimal.*` |
| `en-US` | `Quote/0` | `Early Bird Edition` | `uc8151_minimal.*` |
| `ja-JP` | `Quote/0` | `先発版です` | `uc8151_minimal.*` |

If the device details do not show one of these labels, use the standard edition driver:

```text
uc8251d_minimal.*
```

## SPI Signals

| Signal | GPIO | Direction |
| --- | ---: | --- |
| BUSY | 3 | Input |
| RESET | 4 | Output |
| DC | 5 | Output |
| CS | 6 | Output |
| MOSI | 7 | Output |
| CLK | 10 | Output |
| VIN | 20 | Output |

MISO is not used.

## Refresh Flow

The minimal drivers follow this flow:

1. Enable display power.
2. Reset the panel.
3. Wait until BUSY is ready.
4. Configure panel and power settings.
5. Load the full-refresh LUT.
6. Write the old frame plane.
7. Write the new frame plane.
8. Trigger display update.
9. Wait until BUSY is ready.
10. Enter sleep when requested.

## Waveform/LUT Data

The public full-refresh LUT data is stored in the matching driver source file:

- Standard edition: `uc8251d_minimal.c`
- Early Bird Edition: `uc8151_minimal.c`

See:

```text
firmware-resources/display/waveforms/README.md
```

Use each waveform only with the matching controller and panel configuration unless you have validated another display.

## Common Bring-Up Problems

| Symptom | Things to check |
| --- | --- |
| Display never updates | VIN pin, RESET pin, CS pin, SPI host, MOSI/CLK wiring |
| Firmware times out waiting for BUSY | BUSY pin number, pull-up configuration, panel power |
| Image is inverted | Pixel convention: `1 = white`, `0 = black` |
| Image is shifted or corrupted | Buffer size, row packing, SPI mode, transfer length |
| Display works once and then stops | Sleep path, power control, reset before next update |

## Porting Checklist

- Confirm the display variant from Dot. App device details.
- Use `uc8251d_minimal.*` for standard edition devices.
- Use `uc8151_minimal.*` for Early Bird Edition devices.
- Confirm 152 x 296 resolution.
- Confirm 1bpp framebuffer size.
- Confirm GPIO mapping.
- Confirm SPI mode 0.
- Confirm display power control behavior.
- Confirm BUSY polarity on the actual panel.

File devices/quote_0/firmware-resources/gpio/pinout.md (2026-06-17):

# Quote/0 GPIO Pinout

This document lists the ESP32-C3 GPIOs used by the current Quote/0 hardware design. Use it for firmware bring-up, hardware migration, and debugging.

## Used GPIOs

| GPIO | Function | Direction | Notes |
| --- | --- | --- | --- |
| GPIO0 | VBUS detect | Input | Detects whether USB or external power is connected. High level means external power is present. |
| GPIO1 | Battery voltage sample | Input / ADC | Reads battery voltage through an internal 50% / 50% resistor divider. |
| GPIO3 | E-paper BUSY | Input | Reads the display busy state. |
| GPIO4 | E-paper RESET | Output | Controls display reset. |
| GPIO5 | E-paper DC | Output | Selects command or data for SPI transfers. |
| GPIO6 | E-paper CS | Output | Display SPI chip select. |
| GPIO7 | E-paper MOSI | Output | Display SPI data output. |
| GPIO10 | E-paper CLK | Output | Display SPI clock. |
| GPIO20 | E-paper VIN | Output | Controls display power. |

## Notes

- The e-paper display uses SPI and does not use MISO.
- For custom ESP-IDF firmware, use Pure USB Serial/JTAG console output. The default UART console pins may conflict with `GPIO20`; disable `ESP_CONSOLE_UART_DEFAULT` and enable `ESP_CONSOLE_USB_SERIAL_JTAG`.
- Wi-Fi, Bluetooth LE, and the internal temperature sensor do not require external GPIOs.

## Machine-Readable Files

- `pinout.csv`
- `pinout.json`

## License

Hardware connection information is licensed under CERN-OHL-P-2.0. This documentation is licensed under CC BY 4.0.

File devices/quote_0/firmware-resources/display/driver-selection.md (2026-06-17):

# Quote/0 Display Driver Selection

Quote/0 has two display driver variants. The screen parameters are the same, but the controller firmware and waveform data are different.

Use the wrong display driver only after you have verified the panel yourself. For normal users and firmware ports, choose the driver based on the Dot. App device details.

## Selection Rule

Use the Early Bird Edition driver only when the Dot. App device details show one of these edition labels:

| Dot. App locale | Device name | Edition label | Driver files |
| --- | --- | --- | --- |
| `zh-Hans-CN` | `摘录/0` | `首发版` | `drivers/uc8151_minimal.h`, `drivers/uc8151_minimal.c` |
| `en-US` | `Quote/0` | `Early Bird Edition` | `drivers/uc8151_minimal.h`, `drivers/uc8151_minimal.c` |
| `ja-JP` | `Quote/0` | `先発版です` | `drivers/uc8151_minimal.h`, `drivers/uc8151_minimal.c` |

If the device details do not show one of the labels above, use the standard edition driver:

```text
drivers/uc8251d_minimal.h
drivers/uc8251d_minimal.c
```

## Variant Summary

| Variant | App label | Controller path | Driver files |
| --- | --- | --- | --- |
| Standard edition | No Early Bird Edition label | UC8251D | `uc8251d_minimal.h`, `uc8251d_minimal.c` |
| Early Bird Edition | `首发版` / `Early Bird Edition` / `先発版です` | UC8151/IL0324 | `uc8151_minimal.h`, `uc8151_minimal.c` |

## Shared Display Parameters

Both variants use the same public framebuffer shape:

| Item | Value |
| --- | --- |
| Resolution | 152 x 296 |
| Color mode | Black and white |
| Pixel format | 1 bit per pixel |
| Pixel value | `1 = white`, `0 = black` |
| Framebuffer size | 5,624 bytes |
| Bus | SPI |
| MISO | Not used |

## Why There Are Two Drivers

The two Quote/0 editions use panels with the same visible screen parameters, but their controller firmware and waveform requirements are different. The driver source therefore keeps separate initialization and LUT paths for the standard edition and the Early Bird Edition.

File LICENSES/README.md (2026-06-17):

# License Texts

This directory contains the license texts used by this repository.

| File | License | Default scope |
| --- | --- | --- |
| `Apache-2.0.txt` | Apache License 2.0 | Software source code |
| `CERN-OHL-P-2.0.txt` | CERN Open Hardware Licence Version 2 - Permissive | Hardware design material |
| `CC-BY-4.0.txt` | Creative Commons Attribution 4.0 International | Documentation and media |

See the repository-level `LICENSE.md` for the default license mapping.

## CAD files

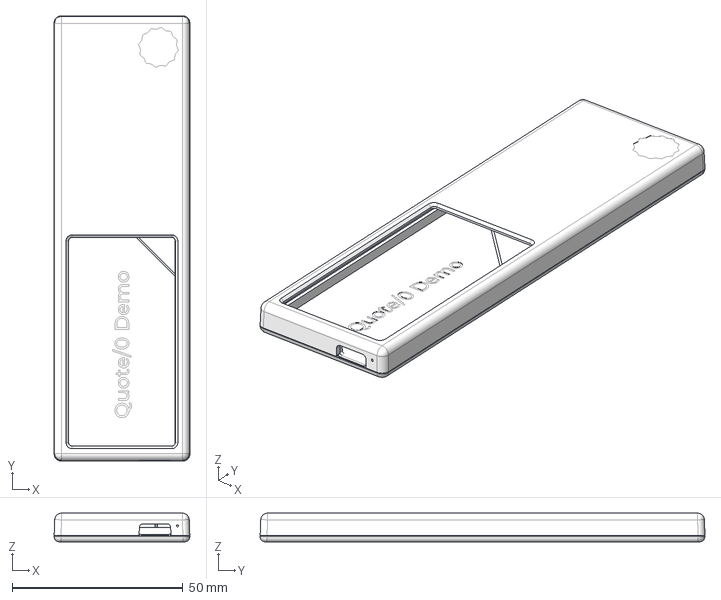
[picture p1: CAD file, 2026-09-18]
devices/quote_0/enclosure/step/quote_0-enclosure.step
39.7 x 130.2 x 8.37 mm

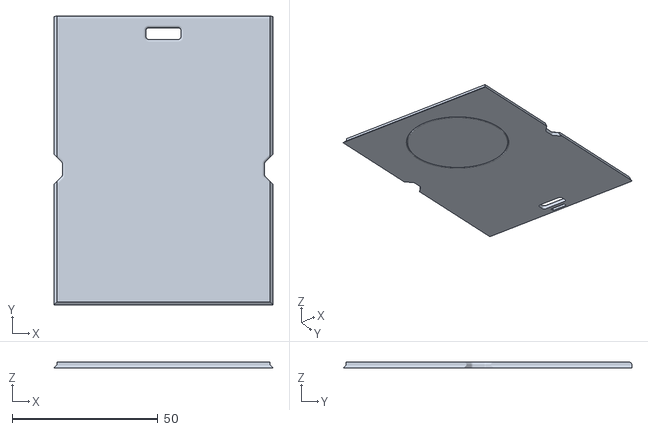
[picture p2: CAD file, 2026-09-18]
devices/quote_0/enclosure/stl/adventurex-2026/quote_0-adventurex-2026-badge-back-cover.stl
75.1 x 99.0 x 2.00

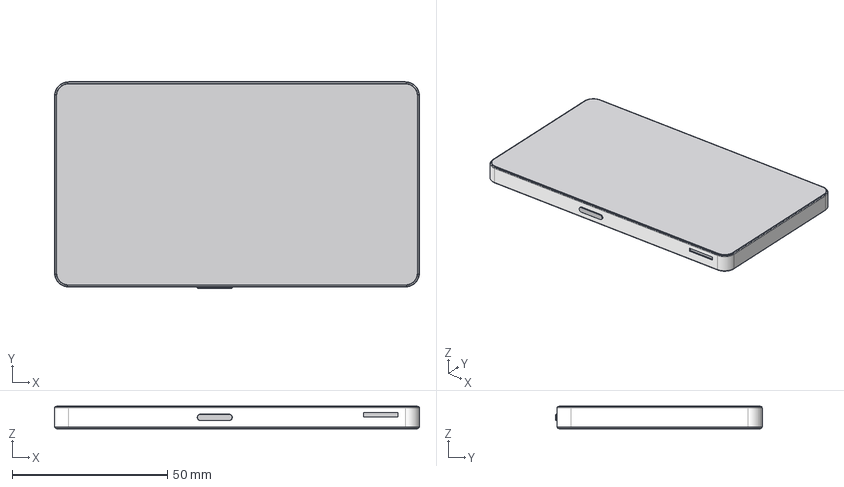
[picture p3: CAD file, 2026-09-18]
devices/read_0/enclosure/step/read_0-enclosure.step
117.5 x 66.4 x 7.40 mm

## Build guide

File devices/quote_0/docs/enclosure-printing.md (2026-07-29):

# Enclosure and Printing Notes

The public enclosure resources are:

| Design | File | Format |
| --- | --- | --- |
| Main Quote/0 enclosure | `enclosure/step/quote_0-enclosure.step` | STEP AP242 |
| AdventureX 2026 badge front shell | `enclosure/stl/adventurex-2026/quote_0-adventurex-2026-badge-front.stl` | Binary STL |
| AdventureX 2026 badge back cover | `enclosure/stl/adventurex-2026/quote_0-adventurex-2026-badge-back-cover.stl` | Binary STL |

The STEP file is exported in millimeter units. STL files do not encode units; import the AdventureX 2026 meshes as millimeters and verify their scale before printing.

## Before Manufacturing

Inspect the model in your CAD tool and verify:

- Overall dimensions.
- Display opening and alignment.
- PCB mounting features.
- Battery clearance.
- Cable or flex routing.
- Button, port, or fastener clearance.
- Wall thickness.
- Assembly order.
- Material and process-specific tolerances.

## 3D Printing

The AdventureX 2026 badge enclosure includes a two-part printable STL set. No official print profile is included.

- Confirm units and scale after import.
- Select a print orientation appropriate for overhangs and supports.
- Check mesh integrity before slicing.
- Print a tolerance test before relying on a final part.
- Re-check fit with the exact display, PCB, battery, and fasteners you use.

## CAD Modification

The main enclosure STEP file is suitable for exchange and downstream mechanical work, but it is not the same as a native parametric CAD source file. The AdventureX 2026 files are triangulated meshes intended primarily for printing.

If you need editable parameters, import the STEP file into your CAD tool and rebuild editable features as needed.

## License

The enclosure file is published as hardware design material under CERN-OHL-P-2.0 unless a file states otherwise.

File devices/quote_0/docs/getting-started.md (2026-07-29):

# Getting Started with Quote/0

This guide gives you the shortest path through the public Quote/0 resource package.

## 1. Inspect the Device Package

Start with:

- `devices/quote_0/README.md`
- `devices/quote_0/manifest.json`

The README is the human-readable landing page. The manifest is intended for platforms, catalogs, and tooling.

## 2. Review the Official Online Context

Use these pages when you want to connect the hardware package to Dot software capabilities:

| Resource | Link |
| --- | --- |
| Developer Platform | https://dot.mindreset.tech/developers |
| Quote/0 product docs | https://dot.mindreset.tech/docs/quote_0 |
| Developer Platform docs | https://dot.mindreset.tech/docs/service/open |
| Content Studio | https://dot.mindreset.tech/docs/service/studio |
| Community Co-Creation | https://dot.mindreset.tech/docs/service/co_create |
| Software Co-Creation | https://dot.mindreset.tech/docs/service/co_create/software |
| Hardware Co-Creation | https://dot.mindreset.tech/docs/service/co_create/hardware |

## 3. Review the Pinout

Read:

- `firmware-resources/gpio/pinout.md`
- `firmware-resources/gpio/pinout.csv`
- `firmware-resources/gpio/pinout.json`

Use the Markdown file for development. Use CSV or JSON for scripts, documentation generators, or platform import.

## 4. Bring Up the Display

Read:

- `firmware-resources/display/README.md`
- `firmware-resources/display/driver-selection.md`
- `firmware-resources/display/drivers/README.md`
- `firmware-resources/display/waveforms/README.md`

Quote/0 has two display driver variants. Use the Early Bird Edition driver only when the Dot. App device details show `首发版`, `Early Bird Edition`, or `先発版です`. Otherwise, use the standard edition driver.

Both drivers target ESP-IDF and the Quote/0 152 x 296 monochrome panel configuration.

## 5. Try the Example

Open:

```text
examples/esp-idf/minimal-display/
```

The example shows a small full-screen refresh path using the standard edition public driver. For Early Bird Edition devices, use the same GPIO mapping and framebuffer format, but switch to the UC8151/IL0324 driver described in `firmware-resources/display/driver-selection.md`.

## 6. Inspect the Enclosure

Review the main enclosure STEP file in your CAD tool:

```text
enclosure/step/quote_0-enclosure.step
```

For the AdventureX 2026 badge enclosure, open both STL parts in your slicing or mesh-editing tool:

```text
enclosure/stl/adventurex-2026/quote_0-adventurex-2026-badge-front.stl
enclosure/stl/adventurex-2026/quote_0-adventurex-2026-badge-back-cover.stl
```

Verify units, dimensions, and tolerances before manufacturing, printing, or modifying an enclosure.

## Safety Notes

- MindReset cannot guarantee the security of custom firmware flashed to devices. Flashing custom firmware voids the device warranty.
- For ESP-IDF custom firmware, use Pure USB Serial/JTAG console output. The default UART console pins may conflict with `GPIO20`; disable `ESP_CONSOLE_UART_DEFAULT` and enable `ESP_CONSOLE_USB_SERIAL_JTAG`.
- Quote/0 does not have a physical reset button. Do not enter deep sleep without a wake timer or external wake trigger.
- If a firmware build leaves the device in deep sleep, disconnect the lithium battery connector (`SH1.0`), connect USB Type-C power, flash corrected firmware, then reconnect the battery.
- When powering on after battery disconnection, connect USB Type-C first and then connect the lithium battery. Repeating that sequence can recover from the battery self-protection state.
- Do not assume battery, charging, thermal, or power behavior from GPIO documentation alone.
- Verify the hardware revision before using these files in production firmware.
- Treat e-paper waveform data as display-specific.
- Do not publish private credentials or supplier-confidential material in examples or issues.

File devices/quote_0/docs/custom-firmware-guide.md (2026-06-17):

# Custom Firmware Guide

This guide explains how to use the public Quote/0 resources when writing your own firmware.

## Custom Firmware Safety and Warranty

MindReset cannot guarantee the security of custom firmware flashed to devices. Flashing custom firmware voids the device warranty.

Before building ESP-IDF firmware, configure the console to use Pure USB Serial/JTAG. The default UART console pins may conflict with `GPIO20`, which controls display power. In `menuconfig`, disable `ESP_CONSOLE_UART_DEFAULT` and enable `ESP_CONSOLE_USB_SERIAL_JTAG`.

Quote/0 does not have a physical reset button. Do not put the device into deep sleep with no wake timer or external wake trigger, because it may not wake on its own. If this happens, disassemble the device, disconnect the lithium battery connector (`SH1.0`), connect USB Type-C power, and flash corrected firmware before reconnecting the battery.

When the battery is disconnected, use this power-on sequence: connect USB Type-C first, then connect the lithium battery. If the device enters the battery self-protection state, disconnect power and repeat this sequence.

## Recommended Bring-Up Order

1. Confirm the hardware revision you are targeting.
2. Review `firmware-resources/gpio/pinout.md`.
3. Review `firmware-resources/display/driver-selection.md`.
4. Configure ESP-IDF console output for Pure USB Serial/JTAG.
5. Bring up USB-Serial-JTAG logs.
6. Configure display power, reset, DC, CS, MOSI, CLK, and BUSY pins.
7. Initialize SPI.
8. Reset the selected panel and wait for BUSY.
9. Load the matching waveform/LUT.
10. Write a white test frame.
11. Write a visible black/white test pattern.
12. Put the display into sleep after refresh.

## Choose the Display Driver

Quote/0 has two display driver variants:

| Edition shown in Dot. App device details | Driver |
| --- | --- |
| No Early Bird Edition label | `uc8251d_minimal.*` |
| `首发版` / `Early Bird Edition` / `先発版です` | `uc8151_minimal.*` |

The GPIO mapping and framebuffer shape are the same, but the initialization sequence and waveform data are different.

## Default Quote/0 Display Configuration

```c
static const uc8251d_config_t display_config = {
    .spi_host = SPI2_HOST,
    .pin_vin = 20,
    .pin_busy = 3,
    .pin_reset = 4,
    .pin_dc = 5,
    .pin_cs = 6,
    .pin_sck = 10,
    .pin_mosi = 7,
    .spi_clock_hz = 15 * 1000 * 1000,
};
```

## Framebuffer Format

The display buffer is exactly:

```text
152 * 296 / 8 = 5624 bytes
```

Each bit maps to one pixel:

- `1` means white
- `0` means black

The minimal driver sends one full frame at a time. It does not include image parsing or layout rendering.

## Battery and Power

`GPIO1` samples battery voltage through a 50% / 50% resistor divider. Account for that divider in firmware before displaying or reporting battery voltage.

`GPIO20` controls display power. Keep it enabled while resetting, writing data, and refreshing the e-paper panel. The minimal drivers release the pin in their matching sleep functions.

## Porting to Other Frameworks

If you are not using ESP-IDF, port these parts:

- GPIO output set direction and level.
- GPIO input read for BUSY.
- SPI write byte and bulk transfer.
- Millisecond delay.
- Timeout handling for BUSY polling.

The command sequence and LUT loading logic must match the display variant. Use `uc8251d_minimal.*` for standard edition devices and `uc8151_minimal.*` for Early Bird Edition devices.

## What the Minimal Driver Does Not Do

- No Wi-Fi or Bluetooth setup.
- No power manager.
- No file system integration.
- No image decoder.
- No partial refresh.
- No multi-display abstraction.
- No application UI.

This keeps the public driver small enough to inspect and port.

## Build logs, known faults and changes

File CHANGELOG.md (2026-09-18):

# Changelog

All notable public releases of the Dot Open Platform repository are documented here.

## 2026-09-18

### Added

- Read Pico enclosure STEP AP242 model in millimeter units, with MindReset attribution and license metadata.
- Read Pico enclosure modification notes, download links, and machine-readable resource inventory.

### Changed

- Added MindReset attribution and license metadata to the Quote/0 STEP and AdventureX 2026 badge STL files, preserving AdventureX design credit and all geometry.

## 2026-08-19

### Added

- Rand/0 Display Mode capability package with a local WebSocket protocol reference and official browser example.

## 2026-07-29

### Added

- Two-part AdventureX 2026 badge enclosure for Quote/0 as binary STL files.

## 2026-06-17

### Added

- Initial Quote/0 open hardware resource package.
- Quote/0 enclosure STEP file exported from Shapr3D in millimeter units.
- ESP32-C3 GPIO pinout in Markdown, CSV, and JSON formats.
- Minimal UC8251D standard edition 152 x 296 monochrome e-paper display driver for ESP-IDF.
- Minimal UC8151/IL0324 Early Bird Edition 152 x 296 monochrome e-paper display driver for ESP-IDF.
- Display driver selection guidance based on the edition label shown in Dot. App device details.
- Display waveform/LUT documentation for the included full-refresh flows.
- ESP-IDF minimal display example.
- Official online links for the Dot Developer Platform, Open APIs, Content Studio, Community Co-Creation, and Quote/0 docs.
- Repository license, notice, contribution, support, security, and GitHub issue templates.

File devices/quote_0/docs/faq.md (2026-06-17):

# FAQ

## Is this the full Quote/0 product firmware?

No. This repository publishes open hardware resources and minimal firmware bring-up files. It does not include complete product firmware or application logic.

## Where are the official software APIs?

Start with the Developer Platform at https://dot.mindreset.tech/developers, then use the Developer Platform docs at https://dot.mindreset.tech/docs/service/open.

The most relevant content APIs are:

- Text API: https://dot.mindreset.tech/docs/service/open/text_api
- Image API: https://dot.mindreset.tech/docs/service/open/image_api
- Canvas API: https://dot.mindreset.tech/docs/service/open/canvas_api
- Skills: https://dot.mindreset.tech/docs/service/open/skill

## Where are community software and hardware examples?

Use Community Co-Creation at https://dot.mindreset.tech/docs/service/co_create.

- Software Co-Creation: https://dot.mindreset.tech/docs/service/co_create/software
- Hardware Co-Creation: https://dot.mindreset.tech/docs/service/co_create/hardware

## Can I write my own firmware?

Yes. Start with the GPIO pinout, display resources, and ESP-IDF example. The public driver is intentionally small so it can be inspected and ported.

## Does custom firmware affect warranty or security?

Yes. MindReset cannot guarantee the security of custom firmware flashed to devices. Flashing custom firmware voids the device warranty.

## Which ESP-IDF console configuration should I use?

Use Pure USB Serial/JTAG console output. The default UART console pins may conflict with `GPIO20`, which controls display power. In `menuconfig`, disable `ESP_CONSOLE_UART_DEFAULT` and enable `ESP_CONSOLE_USB_SERIAL_JTAG`.

## Can I use deep sleep in custom firmware?

Use deep sleep only when your firmware has a reliable wake timer or external wake trigger. Quote/0 does not have a physical reset button, so a build that enters deep sleep with no wake path may not wake on its own.

If this happens, disassemble the device, disconnect the lithium battery connector (`SH1.0`), connect USB Type-C power, and flash corrected firmware before reconnecting the battery.

## What is the correct power-on sequence after disconnecting the battery?

Connect USB Type-C first, then connect the lithium battery. If the device enters the battery self-protection state, disconnect power and repeat this sequence.

## Which display driver should I use?

Use the standard driver unless the Dot. App device details show an Early Bird Edition label.

| Dot. App locale | Device name | Edition label | Driver |
| --- | --- | --- | --- |
| `zh-Hans-CN` | `摘录/0` | `首发版` | `uc8151_minimal.*` |
| `en-US` | `Quote/0` | `Early Bird Edition` | `uc8151_minimal.*` |
| `ja-JP` | `Quote/0` | `先発版です` | `uc8151_minimal.*` |

If no edition label is shown, use `uc8251d_minimal.*`.

## Can I manufacture or sell a derivative?

The included materials are published under open licenses that allow broad reuse. You must follow the license and attribution requirements in `LICENSE.md` and `NOTICE.md`. The licenses do not grant trademark rights.

## Can I use the Quote/0 name or MindReset logo?

You may use names for accurate attribution or compatibility statements. Do not use MindReset names, logos, or product identity in a way that suggests endorsement or official status.

## Are display waveforms redistributable?

This package treats the included standard and Early Bird Edition waveform/LUT data as authorized for public redistribution by MindReset. Do not add other vendor waveforms unless their redistribution rights are clear.

## Why is there no STL file?

The current release includes a STEP file. You can export STL from your CAD tool if needed, then validate print tolerances.

## Does the display use MISO?

No. The public Quote/0 display interface uses MOSI and CLK for SPI writes and does not use MISO.

## What does `GPIO20` do?

`GPIO20` controls display power. The minimal driver enables it during display operations and releases it when entering sleep.

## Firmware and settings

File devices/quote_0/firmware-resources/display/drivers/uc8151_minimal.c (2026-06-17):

/**
 * @file uc8151_minimal.c
 * @brief Minimal UC8151/IL0324 e-paper display driver implementation.
 * @license Apache-2.0
 *
 * Scope:
 * - Uses ESP-IDF SPI master and GPIO APIs to drive UC8151/IL0324.
 * - Implements the fixed 152x296 monochrome full-refresh path for the
 *   Quote/0 Early Bird Edition with only the code needed for public bring-up
 *   and porting.
 */

/* SPDX-License-Identifier: Apache-2.0 */

#include "uc8151_minimal.h"

#include <stdbool.h>
#include <stddef.h>
#include <string.h>
#include "driver/gpio.h"
#include "esp_timer.h"
#include "freertos/FreeRTOS.h"
#include "freertos/task.h"

#define UC8151_BORDER_WHITE_REG  0x97
#define UC8151_BUSY_TIMEOUT_MS   3000
#define UC8151_BUSY_POLL_MS      10
#define UC8151_RESET_DELAY_MS    20
#define UC8151_SLEEP_DELAY_MS    2700

#define UC8151_LUT_VCOM_SIZE     44
#define UC8151_LUT_WW_SIZE       42
#define UC8151_LUT_BW_SIZE       42
#define UC8151_LUT_WB_SIZE       42
#define UC8151_LUT_BB_SIZE       42

static uc8151_config_t s_cfg;
static spi_device_handle_t s_spi;
static bool s_inited;

static const uint8_t s_lut_vcom[UC8151_LUT_VCOM_SIZE] = {
    0x00, 0x08, 0x00, 0x00, 0x00, 0x02,
    0x60, 0x28, 0x28, 0x00, 0x00, 0x01,
    0x00, 0x14, 0x00, 0x00, 0x00, 0x01,
    0x00, 0x12, 0x12, 0x00, 0x00, 0x01,
    0x00, 0x00, 0x00, 0x00, 0x00, 0x00,
    0x00, 0x00, 0x00, 0x00, 0x00, 0x00,
    0x00, 0x00, 0x00, 0x00, 0x00, 0x00,
    0x00, 0x00,
};

static const uint8_t s_lut_ww[UC8151_LUT_WW_SIZE] = {
    0x40, 0x08, 0x00, 0x00, 0x00, 0x02,
    0x90, 0x28, 0x28, 0x00, 0x00, 0x01,
    0x40, 0x14, 0x00, 0x00, 0x00, 0x01,
    0xA0, 0x12, 0x12, 0x00, 0x00, 0x01,
    0x00, 0x00, 0x00, 0x00, 0x00, 0x00,
    0x00, 0x00, 0x00, 0x00, 0x00, 0x00,
    0x00, 0x00, 0x00, 0x00, 0x00, 0x00,
};

static const uint8_t s_lut_bw[UC8151_LUT_BW_SIZE] = {
    0x40, 0x08, 0x00, 0x00, 0x00, 0x02,
    0x90, 0x28, 0x28, 0x00, 0x00, 0x01,
    0x40, 0x14, 0x00, 0x00, 0x00, 0x01,
    0xA0, 0x12, 0x12, 0x00, 0x00, 0x01,
    0x00, 0x00, 0x00, 0x00, 0x00, 0x00,
    0x00, 0x00, 0x00, 0x00, 0x00, 0x00,
    0x00, 0x00, 0x00, 0x00, 0x00, 0x00,
};

static const uint8_t s_lut_wb[UC8151_LUT_WB_SIZE] = {
    0x80, 0x08, 0x00, 0x00, 0x00, 0x02,
    0x90, 0x28, 0x28, 0x00, 0x00, 0x01,
    0x80, 0x14, 0x00, 0x00, 0x00, 0x01,
    0x50, 0x12, 0x12, 0x00, 0x00, 0x01,
    0x00, 0x00, 0x00, 0x00, 0x00, 0x00,
    0x00, 0x00, 0x00, 0x00, 0x00, 0x00,
    0x00, 0x00, 0x00, 0x00, 0x00, 0x00,
};

static const uint8_t s_lut_bb[UC8151_LUT_BB_SIZE] = {
    0x80, 0x08, 0x00, 0x00, 0x00, 0x02,
    0x90, 0x28, 0x28, 0x00, 0x00, 0x01,
    0x80, 0x14, 0x00, 0x00, 0x00, 0x01,
    0x50, 0x12, 0x12, 0x00, 0x00, 0x01,
    0x00, 0x00, 0x00, 0x00, 0x00, 0x00,
    0x00, 0x00, 0x00, 0x00, 0x00, 0x00,
    0x00, 0x00, 0x00, 0x00, 0x00, 0x00,
};

static void delay_ms(uint32_t ms)
{
    vTaskDelay(pdMS_TO_TICKS(ms));
}

static esp_err_t write_byte(uint8_t value)
{
    spi_transaction_t trans = {
        .flags = SPI_TRANS_USE_TXDATA,
        .length = 8,
    };
    trans.tx_data[0] = value;
    return spi_device_polling_transmit(s_spi, &trans);
}

static esp_err_t write_data_bulk(const uint8_t *data, size_t len)
{
    while (len > 0) {
        size_t chunk = (len > 4096) ? 4096 : len;
        spi_transaction_t trans = {
            .length = chunk * 8,
            .tx_buffer = data,
        };
        esp_err_t ret = spi_device_polling_transmit(s_spi, &trans);
        if (ret != ESP_OK) {
            return ret;
        }
        data += chunk;
        len -= chunk;
    }
    return ESP_OK;
}

static esp_err_t cmd(uint8_t value)
{
    gpio_set_level((gpio_num_t)s_cfg.pin_dc, 0);
    return write_byte(value);
}

static esp_err_t data(uint8_t value)
{
    gpio_set_level((gpio_num_t)s_cfg.pin_dc, 1);
    return write_byte(value);
}

static esp_err_t data_bulk(const uint8_t *bytes, size_t len)
{
    gpio_set_level((gpio_num_t)s_cfg.pin_dc, 1);
    return write_data_bulk(bytes, len);
}

static void reset_panel(void)
{
    for (int i = 0; i < 3; i++) {
        gpio_set_level((gpio_num_t)s_cfg.pin_reset, 0);
        delay_ms(UC8151_RESET_DELAY_MS);
        gpio_set_level((gpio_num_t)s_cfg.pin_reset, 1);
        delay_ms(UC8151_RESET_DELAY_MS);
    }
}

static esp_err_t wait_busy(void)
{
    int64_t start_ms = esp_timer_get_time() / 1000;

    while (gpio_get_level((gpio_num_t)s_cfg.pin_busy) == 0) {
        delay_ms(UC8151_BUSY_POLL_MS);
        if ((esp_timer_get_time() / 1000) - start_ms > UC8151_BUSY_TIMEOUT_MS) {
            return ESP_ERR_TIMEOUT;
        }
    }

    delay_ms(200);
    return ESP_OK;
}

static esp_err_t load_lut(void)
{
    esp_err_t ret = cmd(0x20);
    if (ret != ESP_OK) return ret;
    ret = data_bulk(s_lut_vcom, UC8151_LUT_VCOM_SIZE);
    if (ret != ESP_OK) return ret;

    ret = cmd(0x21);
    if (ret != ESP_OK) return ret;
    ret = data_bulk(s_lut_ww, UC8151_LUT_WW_SIZE);
    if (ret != ESP_OK) return ret;

    ret = cmd(0x22);
    if (ret != ESP_OK) return ret;
    ret = data_bulk(s_lut_bw, UC8151_LUT_BW_SIZE);
    if (ret != ESP_OK) return ret;

    ret = cmd(0x23);
    if (ret != ESP_OK) return ret;
    ret = data_bulk(s_lut_wb, UC8151_LUT_WB_SIZE);
    if (ret != ESP_OK) return ret;

    ret = cmd(0x24);
    if (ret != ESP_OK) return ret;
    return data_bulk(s_lut_bb, UC8151_LUT_BB_SIZE);
}

static esp_err_t init_panel_ic(void)
{
    reset_panel();
    delay_ms(30);

    esp_err_t ret = cmd(0x04);
    if (ret != ESP_OK) return ret;
    ret = wait_busy();
    if (ret != ESP_OK) return ret;

    if ((ret = cmd(0x00)) != ESP_OK) return ret;
    if ((ret = data(0xF3)) != ESP_OK) return ret;

    if ((ret = cmd(0x01)) != ESP_OK) return ret;
    if ((ret = data(0x03)) != ESP_OK) return ret;
    if ((ret = data(0x00)) != ESP_OK) return ret;
    if ((ret = data(0x2B)) != ESP_OK) return ret;
    if ((ret = data(0x2B)) != ESP_OK) return ret;
    if ((ret = data(0x03)) != ESP_OK) return ret;

    if ((ret = cmd(0x06)) != ESP_OK) return ret;
    if ((ret = data(0x17)) != ESP_OK) return ret;
    if ((ret = data(0x17)) != ESP_OK) return ret;
    if ((ret = data(0x17)) != ESP_OK) return ret;

    if ((ret = cmd(0x30)) != ESP_OK) return ret;
    if ((ret = data(0x3A)) != ESP_OK) return ret;

    if ((ret = cmd(0x61)) != ESP_OK) return ret;
    if ((ret = data(0x98)) != ESP_OK) return ret;
    if ((ret = data(0x01)) != ESP_OK) return ret;
    if ((ret = data(0x28)) != ESP_OK) return ret;

    if ((ret = cmd(0x82)) != ESP_OK) return ret;
    if ((ret = data(0x00)) != ESP_OK) return ret;

    ret = wait_busy();
    if (ret != ESP_OK) return ret;

    if ((ret = cmd(0x50)) != ESP_OK) return ret;
    if ((ret = data(UC8151_BORDER_WHITE_REG)) != ESP_OK) return ret;

    return load_lut();
}

static esp_err_t update_panel(void)
{
    esp_err_t ret = cmd(0x12);
    if (ret != ESP_OK) {
        return ret;
    }
    delay_ms(100);
    return wait_busy();
}
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

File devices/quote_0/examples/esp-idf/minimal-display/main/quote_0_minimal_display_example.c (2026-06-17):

/* SPDX-License-Identifier: Apache-2.0 */

#include <stdbool.h>
#include <stdint.h>
#include <string.h>

#include "driver/spi_master.h"
#include "esp_err.h"
#include "uc8251d_minimal.h"

static const uc8251d_config_t display_config = {
    .spi_host = SPI2_HOST,
    .pin_vin = 20,
    .pin_busy = 3,
    .pin_reset = 4,
    .pin_dc = 5,
    .pin_cs = 6,
    .pin_sck = 10,
    .pin_mosi = 7,
    .spi_clock_hz = 15 * 1000 * 1000,
};

static void draw_border(uint8_t *frame)
{
    memset(frame, 0xFF, UC8251D_BUFFER_SIZE);

    for (int y = 0; y < UC8251D_HEIGHT; y++) {
        for (int x = 0; x < UC8251D_WIDTH; x++) {
            bool border = (x < 4) ||
                          (x >= UC8251D_WIDTH - 4) ||
                          (y < 4) ||
                          (y >= UC8251D_HEIGHT - 4);
            if (!border) {
                continue;
            }

            int pixel_index = y * UC8251D_WIDTH + x;
            frame[pixel_index / 8] &= (uint8_t)~(1U << (7 - (pixel_index % 8)));
        }
    }
}

void app_main(void)
{
    static uint8_t frame[UC8251D_BUFFER_SIZE];

    ESP_ERROR_CHECK(uc8251d_init(&display_config));
    ESP_ERROR_CHECK(uc8251d_clear(true));

    draw_border(frame);
    ESP_ERROR_CHECK(uc8251d_display(frame));
    ESP_ERROR_CHECK(uc8251d_sleep());
}

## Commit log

2026-06-17 Initial Quote/0 open hardware package
    [pinout.csv, quote_0-enclosure.step]
2026-06-17 Add Quote/0 early bird display driver
2026-06-17 docs(quote_0): update custom firmware safety and warranty information
    Clarify that flashing custom firmware voids the device warranty and may affect security. Include detailed instructions for console configuration and power-on sequence after battery disconnection.
2026-07-29 Add AdventureX 2026 badge enclosure STL files
    [quote_0-adventurex-2026-badge-back-cover.stl]
2026-09-17 docs: add Read/0 (Pico) resources and documentation
2026-09-17 docs: update Read Pico references in README and manifest files
2026-09-18 feat(hardware): add Read Pico enclosure and CAD attribution
    - Add the Read Pico STEP AP242 enclosure model for custom cases and accessories.
    - Add enclosure documentation, download links, and manifest entries.
    - Add MindReset attribution and license metadata to Read Pico and Quote/0 STEP files.
    - Add attribution and license metadata to AdventureX 2026 STL files, preserving AdventureX design credit.
    - Remove private export paths from STEP headers without changing geometry.
    [quote_0-adventurex-2026-badge-back-cover.stl, quote_0-enclosure.step, read_0-enclosure.step]

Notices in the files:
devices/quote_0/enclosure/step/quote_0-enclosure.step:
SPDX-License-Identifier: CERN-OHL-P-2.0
